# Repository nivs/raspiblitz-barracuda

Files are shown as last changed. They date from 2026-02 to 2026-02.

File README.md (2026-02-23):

[](https://github.com/user-attachments/assets/af210934-4651-4c5d-a316-91d5e0f595a6)

# RaspiBlitz Barracuda

A custom-built [RaspiBlitz](https://github.com/rootzoll/raspiblitz) - a DIY Bitcoin full node running together with a Lightning node on a Raspberry Pi - housed in a 3D-printed chassis with UPS battery backup, fan control, and an LCD touchscreen.

## Components

| Component | Notes |
|---|---|
| [Raspberry Pi 4](https://www.amazon.com/dp/B07TC2BK1X) (4GB or 8GB) | Main board |
| [SanDisk SSD PLUS 1TB](https://www.amazon.com/dp/B09NQJMW28) | Blockchain storage |
| [UGREEN 2.5" Hard Drive Enclosure](https://www.amazon.com/dp/B06XWRRMYX) | SSD enclosure |
| MicroSD Card 32GB | Boot drive |
| [Waveshare 3.5" RPi LCD (B)](https://www.waveshare.com/wiki/3.5inch_RPi_LCD_(B)) | Touchscreen display |
| [Raspberry Pi 4 Official PSU](https://www.amazon.com/dp/B07W8XHMJZ) | 15W USB-C power supply |
| [Dual Fan Heatsink Case](https://www.amazon.com/dp/B07VWM4J4L) | Cooling |
| [UPS Lite 18650](https://www.aliexpress.com/item/32955634965.html) ([GitHub](https://github.com/linshuqin329/UPS-18650-Lite)) | Battery backup |
| [USB 3.0 Micro-B Ribbon Cable](https://www.aliexpress.com/item/4001289178964.html) (S3-W7, USB-A male down, Micro-B up, 0.1m) | SSD connection |
| 40 Pin Stacking Header (8/6mm) | LCD clearance over heatsink |
| 4010 Cooling Fan 40mm | Additional cooling |
| Micro Mini JST 2.0 PH Connectors (3 & 4 pin) | UPS / fan wiring |
| 12mm LED Momentary Switch (6V, Yellow) | Power/reset button |
| 30 & 24 AWG Flexible Silicone Wire | Internal wiring |

<br>

## Setup

Follow the RaspiBlitz [setup instructions](https://docs.raspiblitz.org/docs/setup/intro) to install the software, then apply the hardware customizations below.

A full [connections schematic](raspiblitz-barracuda-connections.pdf) is included in the repo.
<br><br>

## 3D-Printed Chassis

Print files are in the [`chassis/`](chassis/) directory:

- `chassis.3mf` - main enclosure
- `cover.3mf` - top cover
- `lightning-bolt.3mf` - decorative emblem
- `barracuda.f3d` - Fusion 360 source

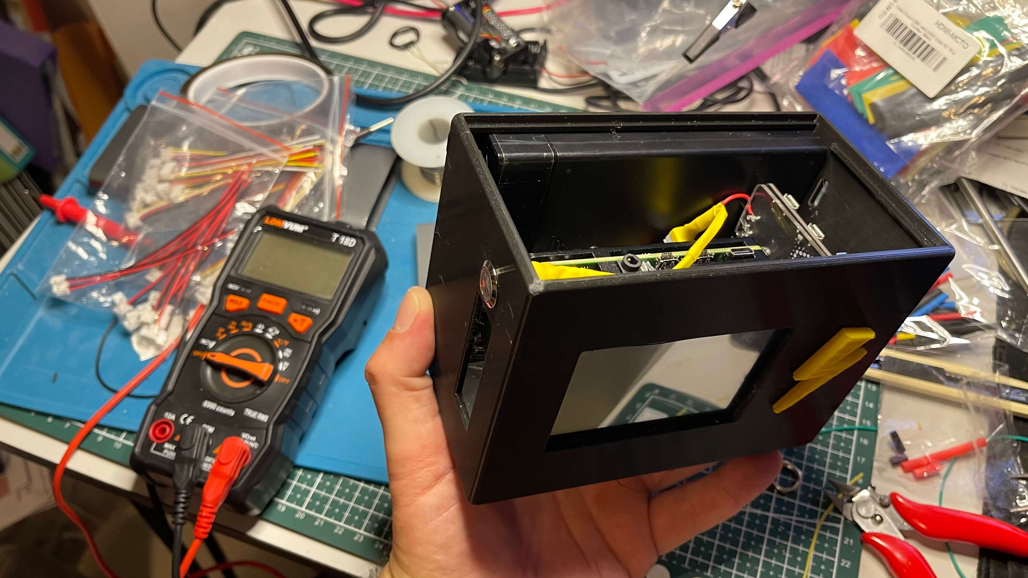
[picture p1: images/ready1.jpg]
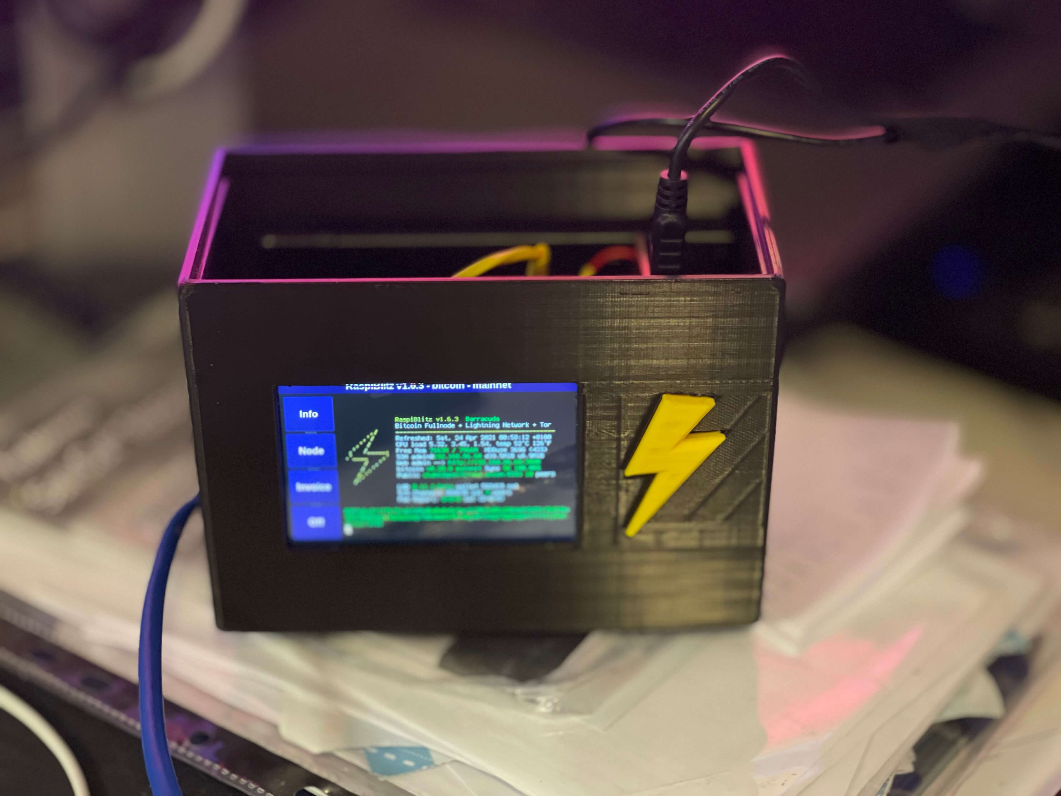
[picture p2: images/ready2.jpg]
 
<br><br>

## Power-On / Reset Switch

Connect a momentary switch between **GPIO3** and **GND**. Use a switch with an integrated LED for the activity indicator.

Alternatively, you can connect the momentary switch to the UPS's power switch, but this is suboptimal as it will not trigger the `gpio-shutdown` event.

See [SHUTDOWN.md](SHUTDOWN.md) for more details.

### Activity LED

1. Connect an LED to **GPIO16** via a 220 ohm resistor.
2. Add to `/boot/config.txt`:
   ```
   dtparam=act_led_gpio=16
   ```

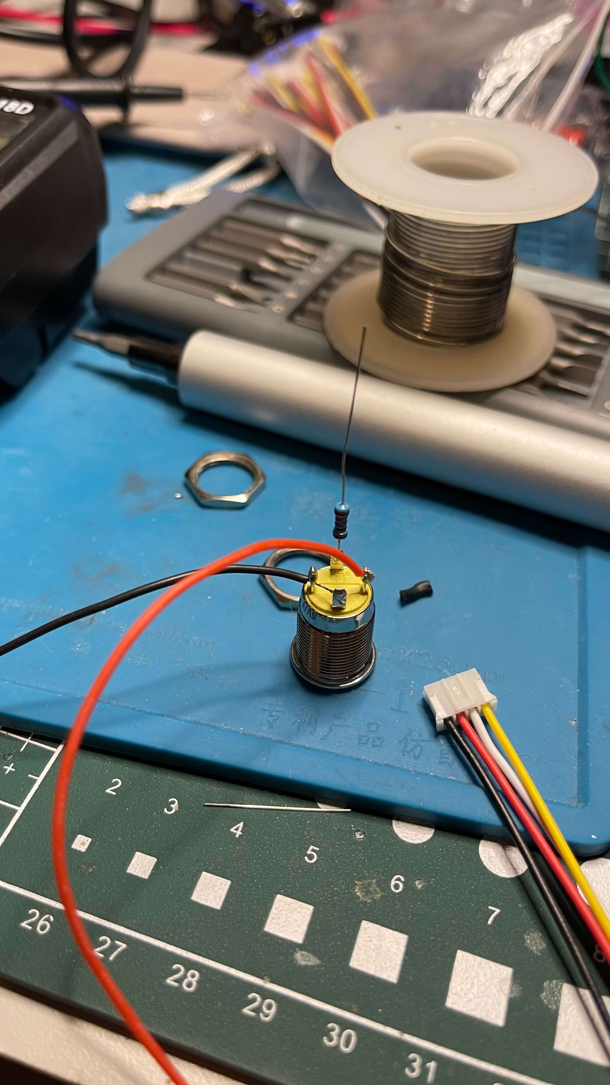
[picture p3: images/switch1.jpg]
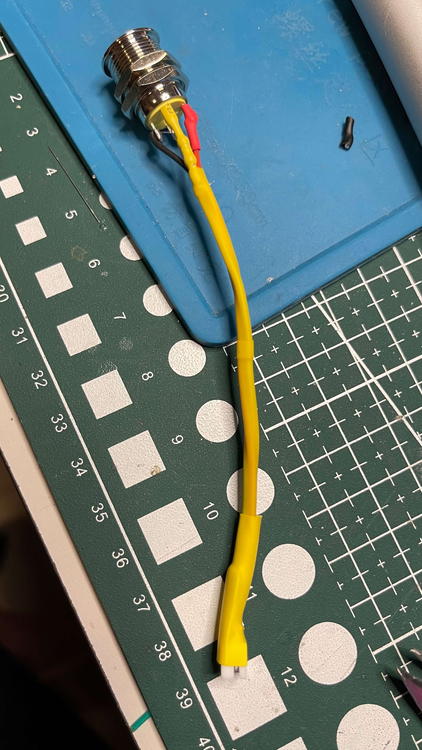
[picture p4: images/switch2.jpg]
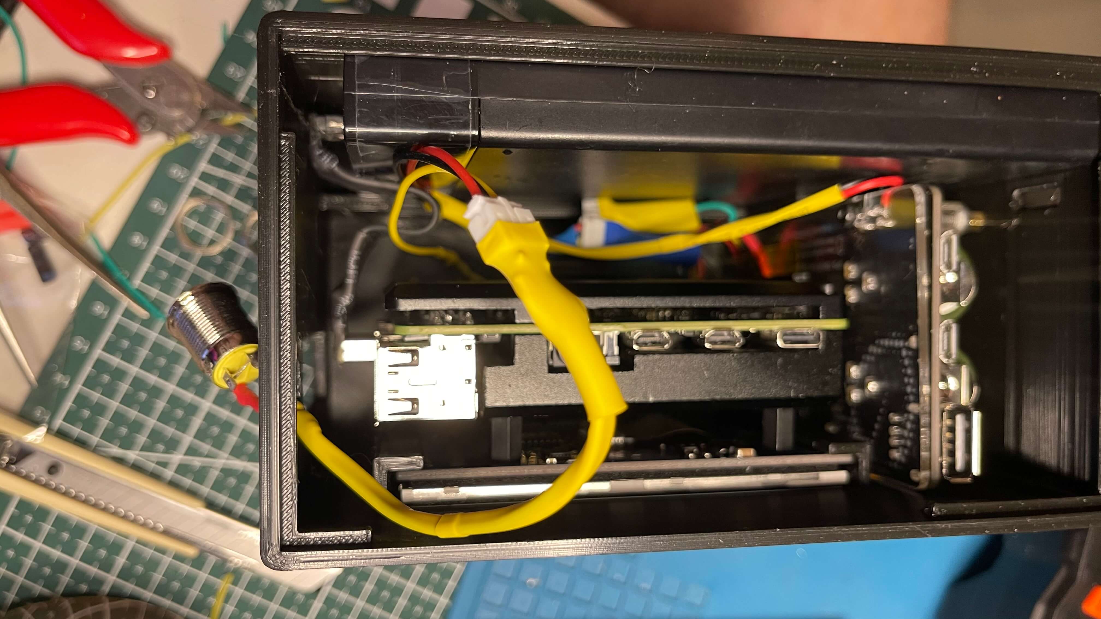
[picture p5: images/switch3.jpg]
  
<br><br>

## Fan Control

Connect **GPIO14** via a 1k ohm resistor to a BC547 transistor to switch the fans (heatsink case fans or an additional external one).

Add to `/boot/config.txt`:
```
dtoverlay=gpio-fan,gpiopin=14,temp=60000
```

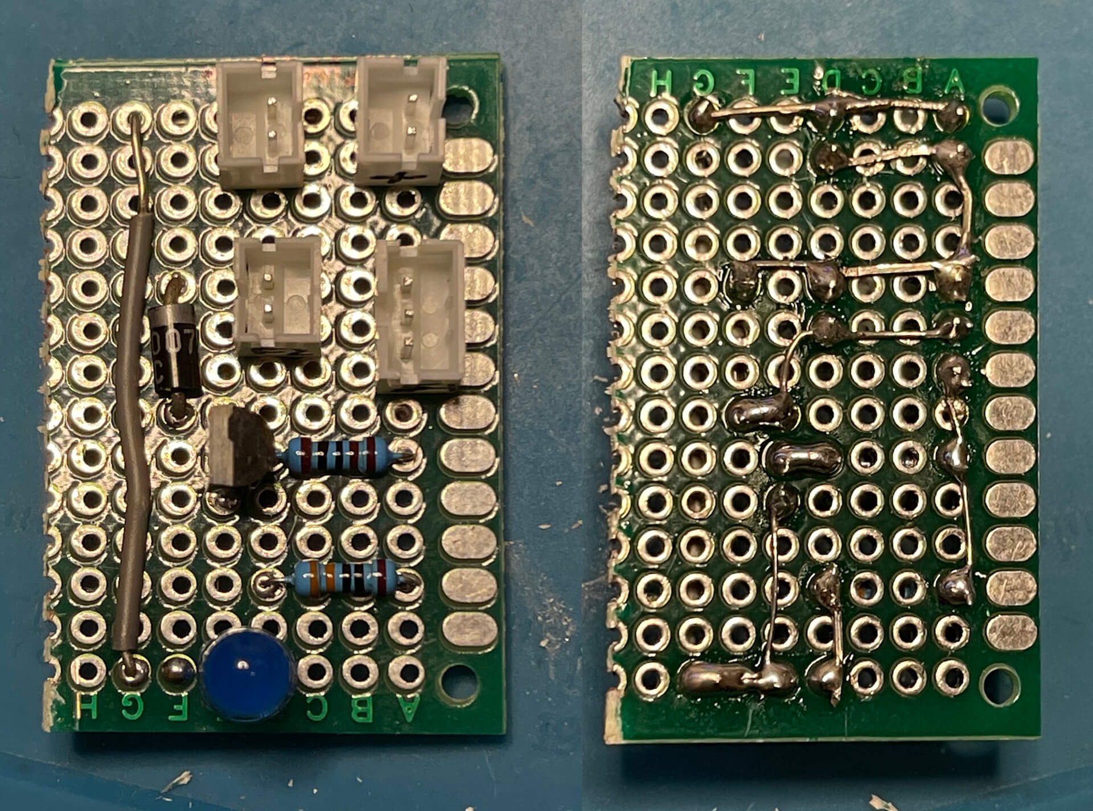
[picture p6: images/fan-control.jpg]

<br>

## LCD

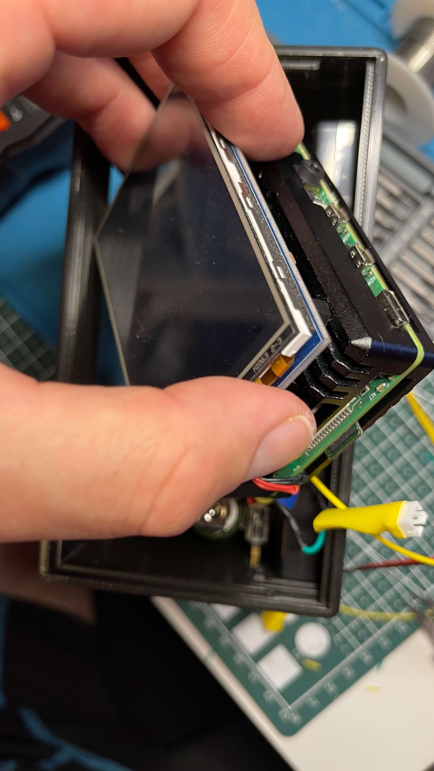
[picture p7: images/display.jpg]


Follow the [Waveshare setup instructions](https://www.waveshare.com/wiki/3.5inch_RPi_LCD_(B)#Software_Settings).

### Backlight Brightness

1. Short the jumper as described in the [Waveshare documentation](https://www.waveshare.com/wiki/3.5inch_RPi_LCD_(B)#Control_Backlight_Brightness_Using_GPIO).
2. Use [`brightness.sh`](brightness.sh) to set brightness (0–1024):
   ```bash
   ./brightness.sh 800
   ```
<br>

## UPS Lite 18650

In this build the UPS Lite is **not** mounted as a HAT - it is wired directly:

- **GPIO2 / GPIO3 (I2C)** - battery state readout
- **GPIO4** - external power detection

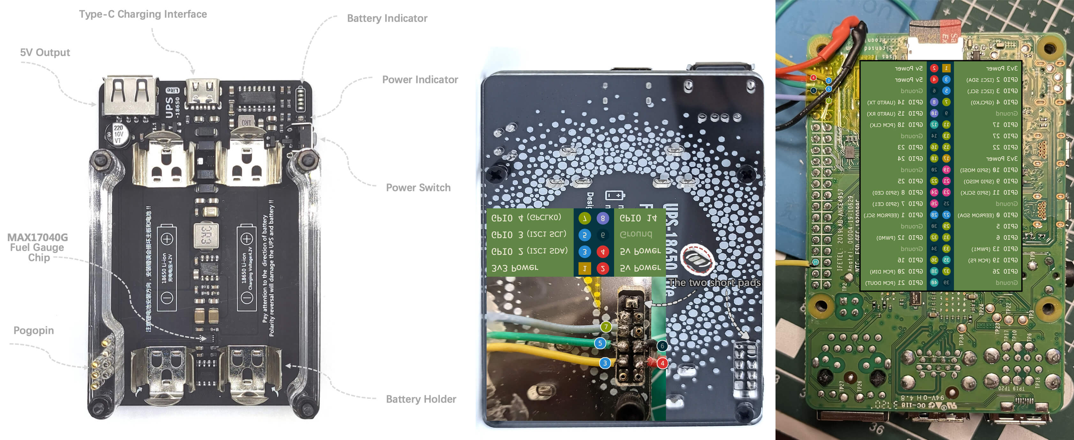
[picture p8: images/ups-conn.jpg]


See the [wiring photo](images/ups-conn.jpg).

### External Power Detection

Short the jumper as described in the [UPS Lite documentation](UPS-18650-Lite/Instructions%20for%20UPS-18650-Lite%20V1.2.pdf). The external power state can be read via **GPIO4**.

### Auto Shutdown

A systemd service monitors battery capacity and triggers a safe shutdown at 1% to prevent data corruption before the hardware protection cuts power.

#### Setup

1. **Enable I2C:**
   ```bash
   # Add or uncomment in /boot/config.txt:
   dtparam=i2c_arm=on

   # Add to /etc/modules (if not already present):
   echo "i2c-dev" | sudo tee -a /etc/modules

   sudo reboot
   ```
2. **Verify I2C** (should show `0x36` for the MAX17040G fuel gauge):
   ```bash
   sudo apt install -y i2c-tools
   sudo i2cdetect -y 1
   ```
3. **Install the monitor service:**
   ```bash
   cp UPS-18650-Lite/ups_shutdown.py /home/pi/
   sudo cp UPS-18650-Lite/ups_monitor.service /etc/systemd/system/
   sudo systemctl daemon-reload
   sudo systemctl enable --now ups_monitor.service
   ```
4. **Verify:**
   ```bash
   sudo systemctl status ups_monitor.service
   sudo journalctl -u ups_monitor.service -n 50
   ```

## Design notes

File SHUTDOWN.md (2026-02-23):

# Shutdown Raspberry Pi with a Single Button

Connect [Boot Button](https://pinout.xyz/pinout/pin5_gpio3#) via a momentary switch to GND:
- Physical/Board pin 5 - GPIO/BCM pin 3 (this is [I2C](https://pinout.xyz/pinout/i2c#)1/SCL, so I2C will be disturbed by a button press)
- GND pin 6

## Boot Overlay

In system version 225 and above, power-down and power-up is possible via shorting [GPIO3 (pin 5)](https://pinout.xyz/pinout/pin5_gpio3#). 
This functionality is enabled by adding the following line to `/boot/config.txt` and restarting:

```
dtoverlay=gpio-shutdown,gpio_pin=3
```

Note: the qualifier `gpio_pin=3` is redundant since this pin is the default.

GPIO3 has an external pull-up, so shorting to ground briefly will initiate a shutdown.  
A subsequent short to ground (provided power is still applied) will power-on the system.

The [boot overlay documentation](https://github.com/raspberrypi/firmware/blob/master/boot/overlays/README) for this function is as follows:

```
Name:   gpio-shutdown
Info:   Initiates a shutdown when GPIO pin changes. The given GPIO pin
        is configured as an input key that generates KEY_POWER events.

        This event is handled by systemd-logind by initiating a
        shutdown. Systemd versions older than 225 need an udev rule
        enable listening to the input device:

                ACTION!="REMOVE", SUBSYSTEM=="input", KERNEL=="event*", \
                        SUBSYSTEMS=="platform", DRIVERS=="gpio-keys", \
                        ATTRS{keys}=="116", TAG+="power-switch"

        Alternatively this event can be handled also on systems without
        systemd, just by traditional SysV init daemon. KEY_POWER event
        (keycode 116) needs to be mapped to KeyboardSignal on console
        and then kb::kbrequest inittab action which is triggered by
        KeyboardSignal from console can be configured to issue system
        shutdown. Steps for this configuration are:

            Add following lines to the /etc/console-setup/remap.inc file:

                # Key Power as special keypress
                keycode 116 = KeyboardSignal

            Then add following lines to /etc/inittab file:

                # Action on special keypress (Key Power)
                kb::kbrequest:/sbin/shutdown -t1 -a -h -P now

            And finally reload configuration by calling following commands:

                # dpkg-reconfigure console-setup
                # service console-setup reload
                # init q

        This overlay only handles shutdown. After shutdown, the system
        can be powered up again by driving GPIO3 low. The default
        configuration uses GPIO3 with a pullup, so if you connect a
        button between GPIO3 and GND (pin 5 and 6 on the 40-pin header),
        you get a shutdown and power-up button. Please note that
        Raspberry Pi 1 Model B rev 1 uses GPIO1 instead of GPIO3.
Load:   dtoverlay=gpio-shutdown,<param>=<val>
Params: gpio_pin                GPIO pin to trigger on (default 3)
                                For Raspberry Pi 1 Model B rev 1 set this
                                explicitly to value 1, e.g.:

                                    dtoverlay=gpio-shutdown,gpio_pin=1

        active_low              When this is 1 (active low), a falling
                                edge generates a key down event and a
                                rising edge generates a key up event.
                                When this is 0 (active high), this is
                                reversed. The default is 1 (active low).

        gpio_pull               Desired pull-up/down state (off, down, up)
                                Default is "up".

                                Note that the default pin (GPIO3) has an
                                external pullup. Same applies for GPIO1
                                on Raspberry Pi 1 Model B rev 1.

        debounce                Specify the debounce interval in milliseconds
                                (default 100)
```

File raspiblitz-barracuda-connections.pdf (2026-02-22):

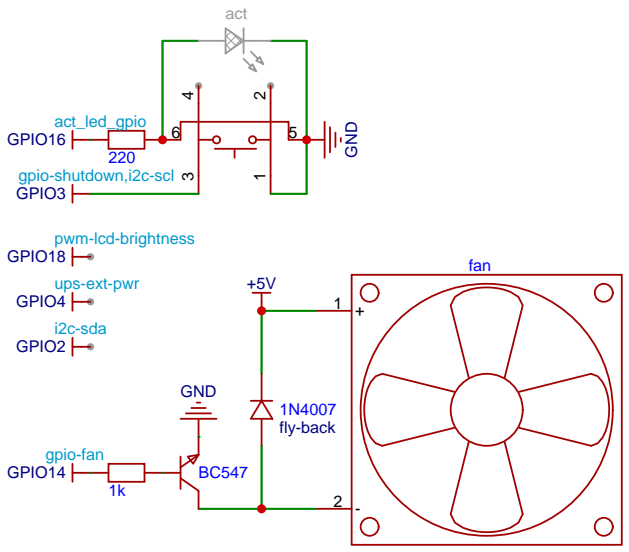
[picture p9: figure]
fan; 1N4007 fly-back; GPIO14; gpio-fan; GND; GPIO16; act_led_gpio; GPIO3; gpio-shutdown,i2c-scl; GPIO18; pwm-lcd-brightness; GPIO4; ups-ext-pwr; GPIO2; i2c-sda; act

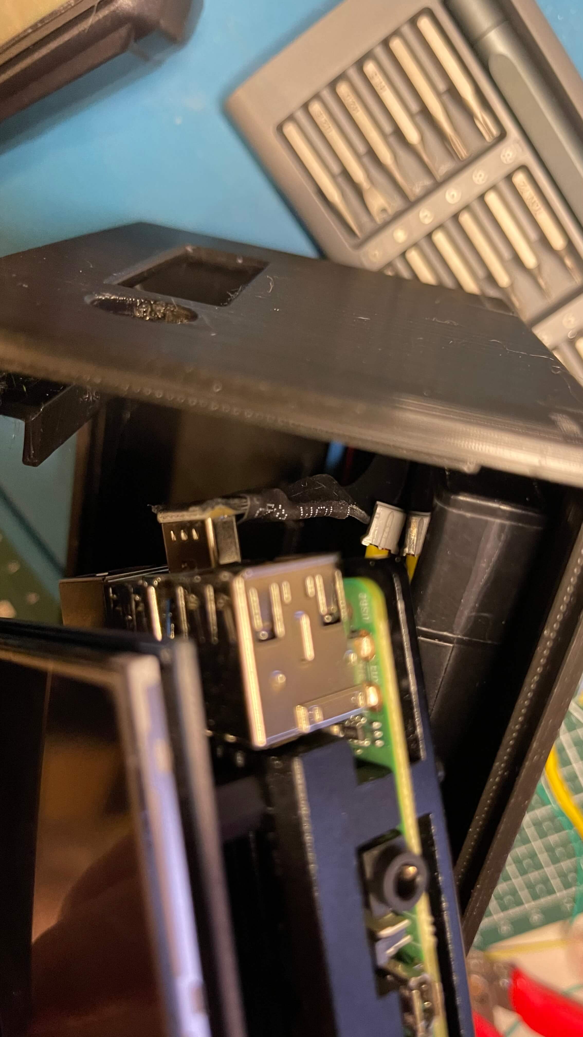
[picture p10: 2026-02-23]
images/usb-c-ribbon2.jpg

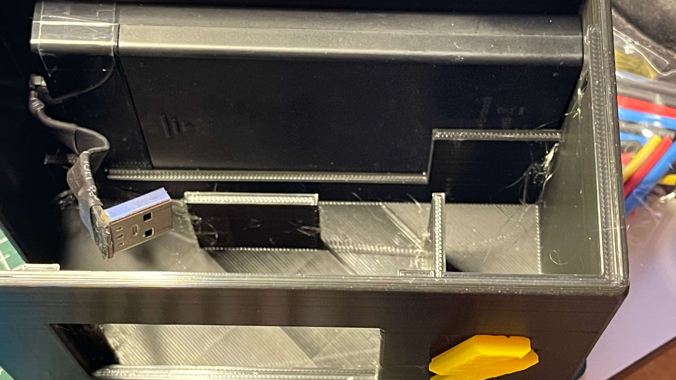
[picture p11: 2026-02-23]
images/usb-c-ribbon1.jpg

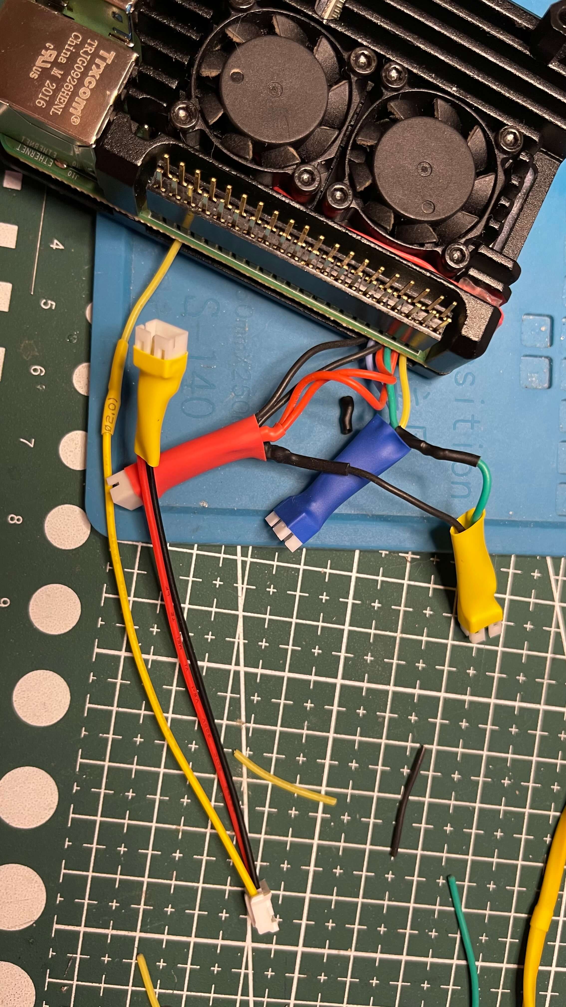
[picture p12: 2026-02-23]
images/raspberry-pi-conn.jpg

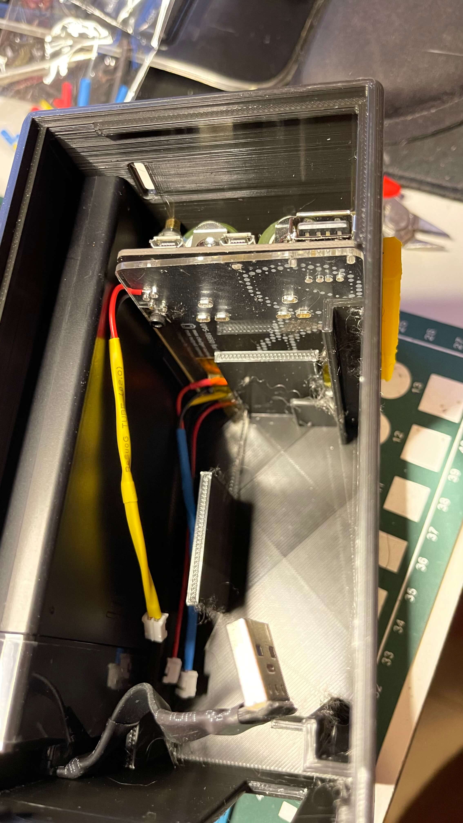
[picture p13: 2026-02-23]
images/ups-hdd.jpg

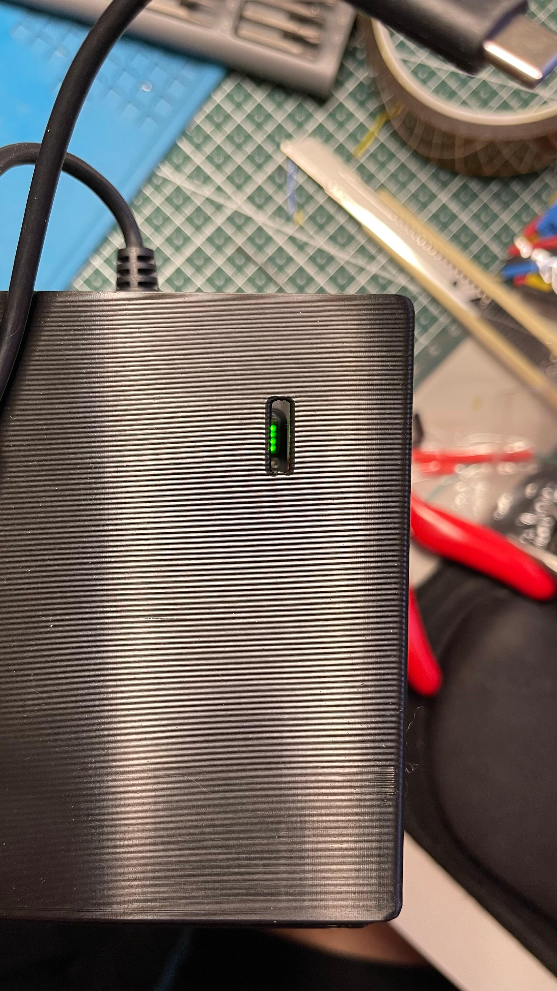
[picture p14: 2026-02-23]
images/ups-battery-indicator.jpg

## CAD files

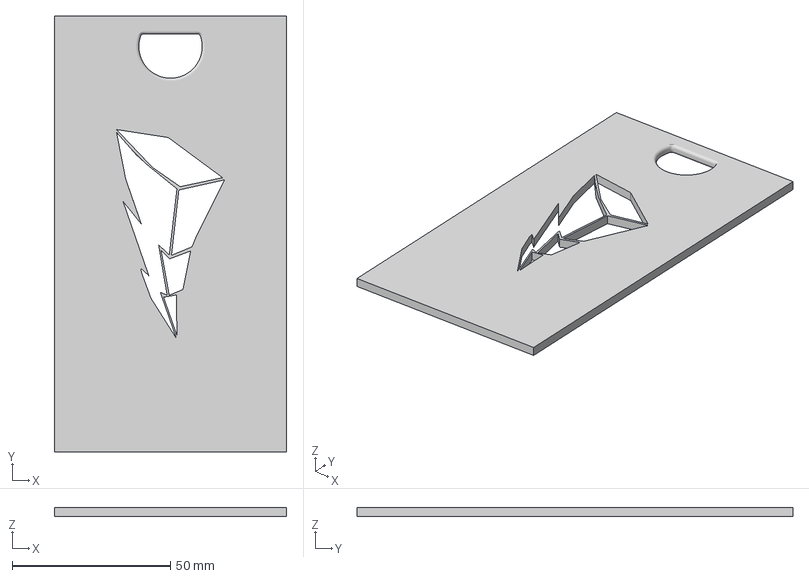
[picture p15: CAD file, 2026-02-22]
chassis/cover.3mf
73.4 x 137.9 x 3.00 mm

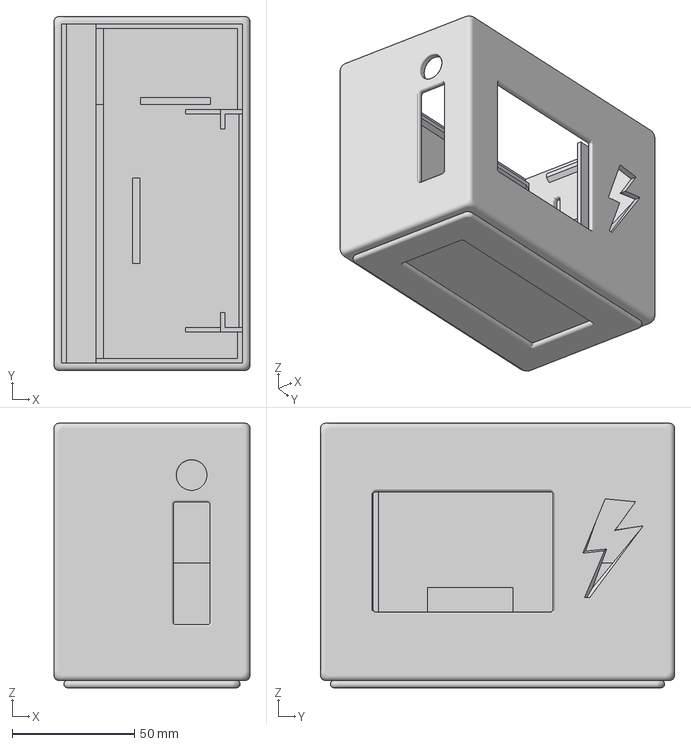
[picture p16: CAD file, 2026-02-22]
chassis/chassis.3mf
80.0 x 144.5 x 108.0 mm

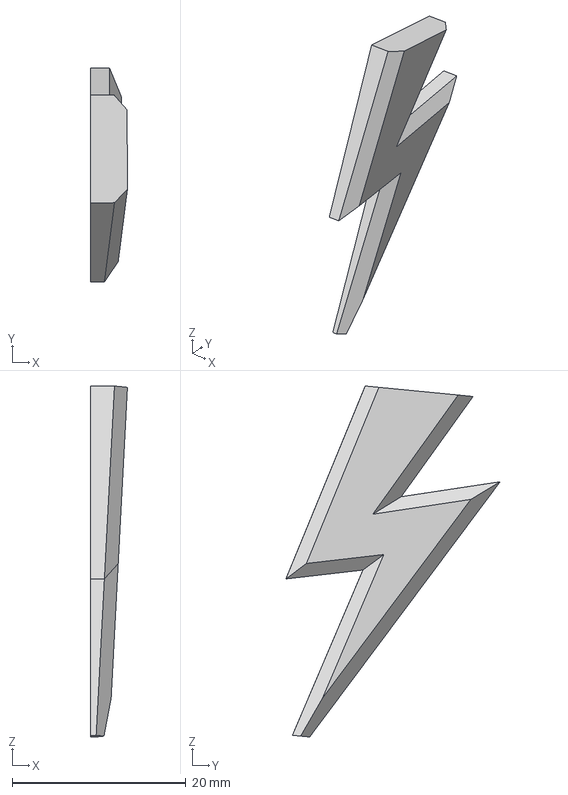
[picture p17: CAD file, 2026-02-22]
chassis/lightning-bolt.3mf
4.25 x 24.7 x 40.4 mm

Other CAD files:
chassis/barracuda.f3d

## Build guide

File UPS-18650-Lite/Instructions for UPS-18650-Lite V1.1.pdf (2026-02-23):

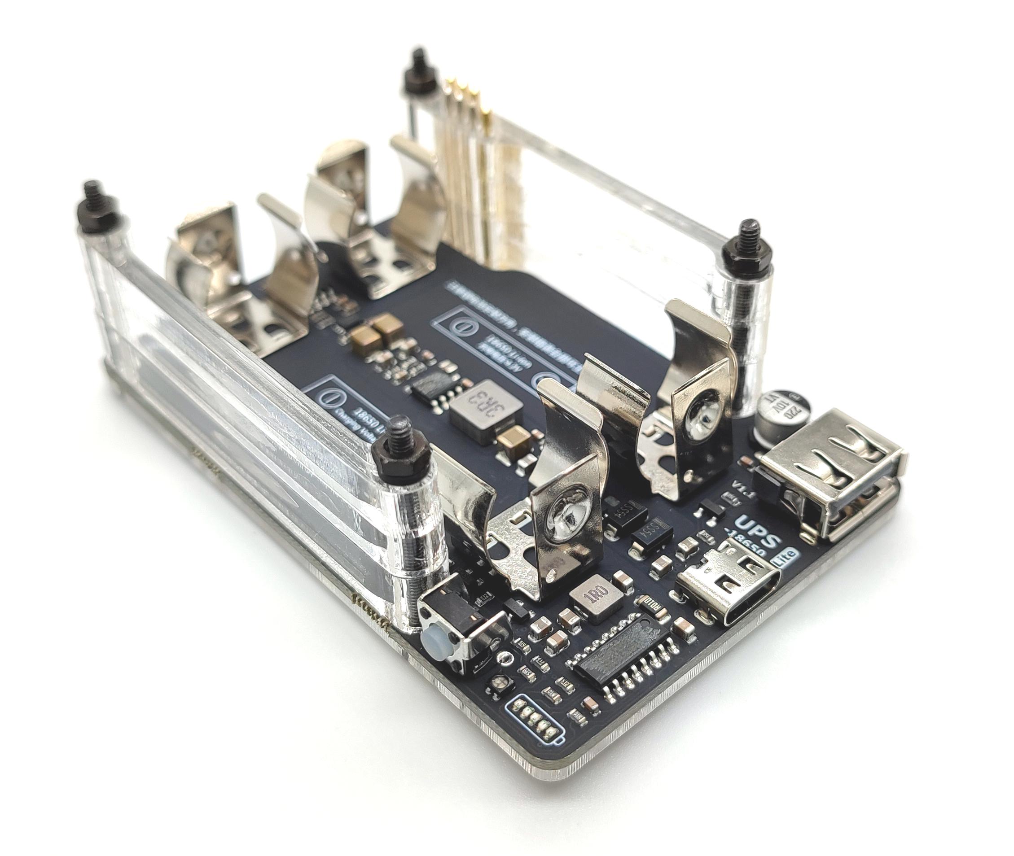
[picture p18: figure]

# 1. Introduction

UPS-18650-Lite is a UPS power supply specially designed for Raspberry Pi model B series boards (namely 4B/3B+/3B, etc., hereinafter referred to as pi). It uses two standard flat-head 18650 lithium batteries for power supply. It support over-charge, over-discharge, over-current, short-circuit protection, support external power plug-in detection, support charging and discharging, when the external power is plugged in, the pi is powered by the external power source, when the external power source is unplugged, the pi seamlessly switches to the lithium battery power supply . UPS-18650-Lite is connected to the pi through 7 pogopins. The power supply and battery power measurement functions of the pi are all done

through pogopins. The pi does not need to plug any power cords, just plug the external power cord into the UPS type-C port ,it can complete power supply and charging by the UPS. In addition, UPS-18650-Lite integrates the professional fuel gauge chip MAX17040G, which can be used to measure UPS battery voltage and battery remaining power.

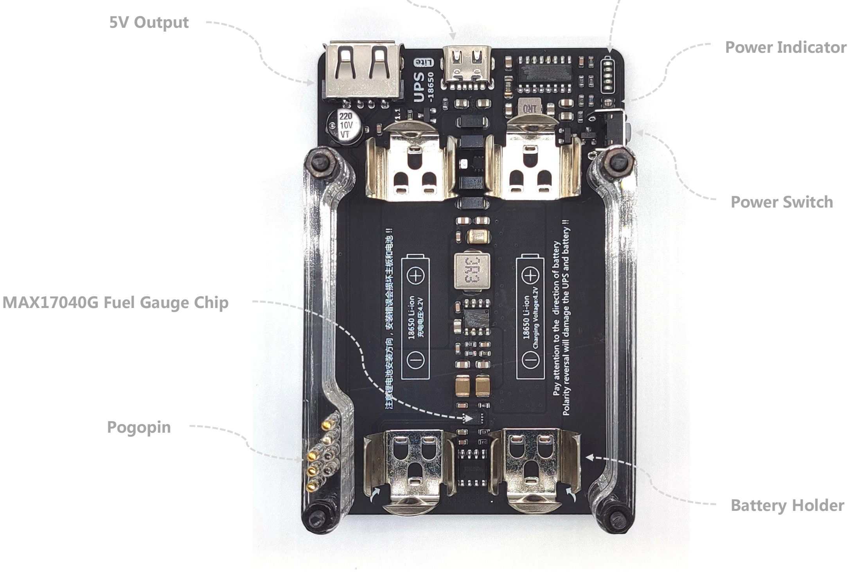
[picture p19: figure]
Power Indicator 5V Output; MAX17040G Fuel Gauge Chip

Battery Holder

Power Switch

Battery Indicator Type-C Charging Interface

Pogopin

Parameter :
Charging current: Max 1A@5V
Output current: Instant Discharge 3.5A@5.1V, Continuous Discharge 2.5A@5.1V
(PS: Please use good quality batteries and power adapters to ensure that the UPS works normally)

Battery measurement: Percentage of battery SOC, an error ±2%, The measurement errors of battery voltages ± 3mV

(PS: The measurement error varies with the individual battery and the ambient temperature)

# 2. Install

a. Please install two 18650 lithium batteries in the direction of the battery logo on the board. Pay attention to the battery direction when installing. Incorrect installation will burn the board and the battery! ! ! (PS: The two lithium batteries must be standard flat-head 18650 batteries of the same type with similar internal resistance and capacity. Two lithium batteries with different parameters cannot be mixed, and lithium batteries with protective plates cannot be used)

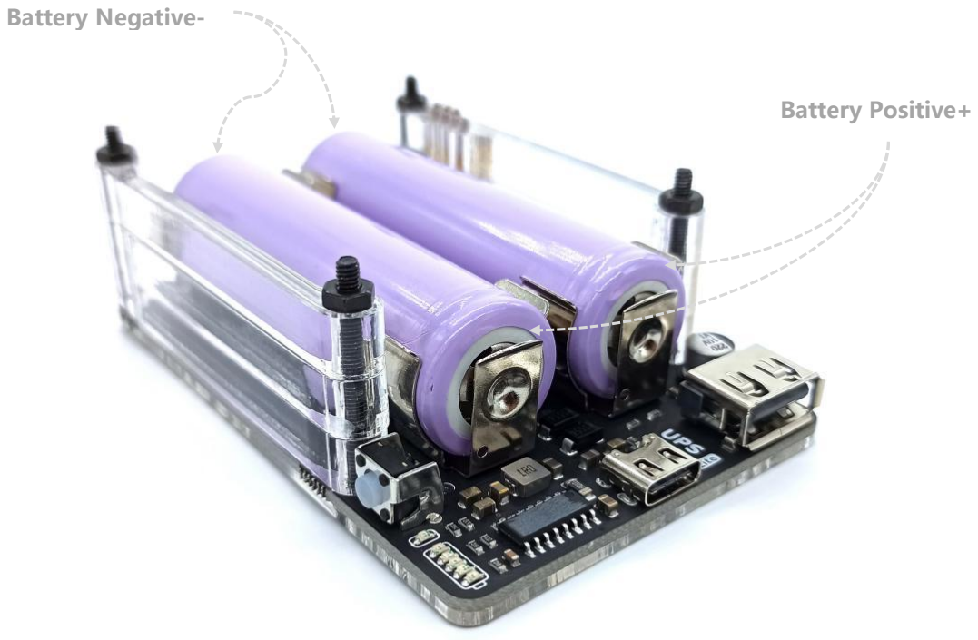
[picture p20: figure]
Battery Negative-; Battery Positive+
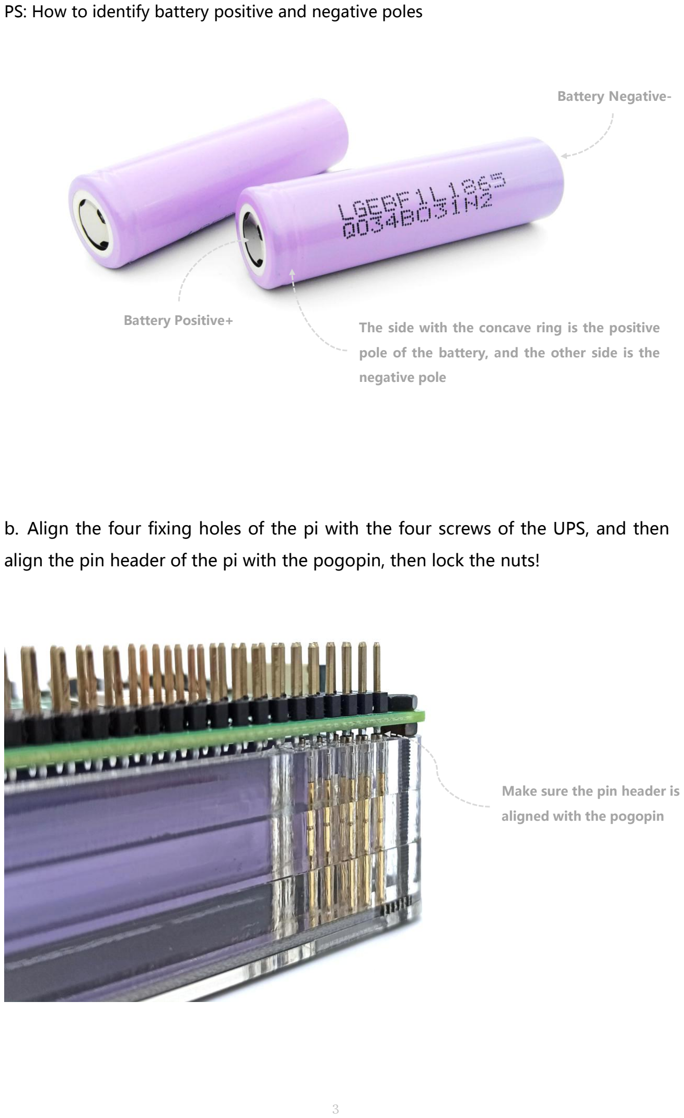
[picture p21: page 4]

PS: How to identify battery positive and negative poles

b. Align the four fixing holes of the pi with the four screws of the UPS, and then align the pin header of the pi with the pogopin, then lock the nuts!

Battery Positive+

Battery Negative-

Make sure the pin header is aligned with the pogopin

The side with the concave ring is the positive pole of the battery, and the other side is the negative pole

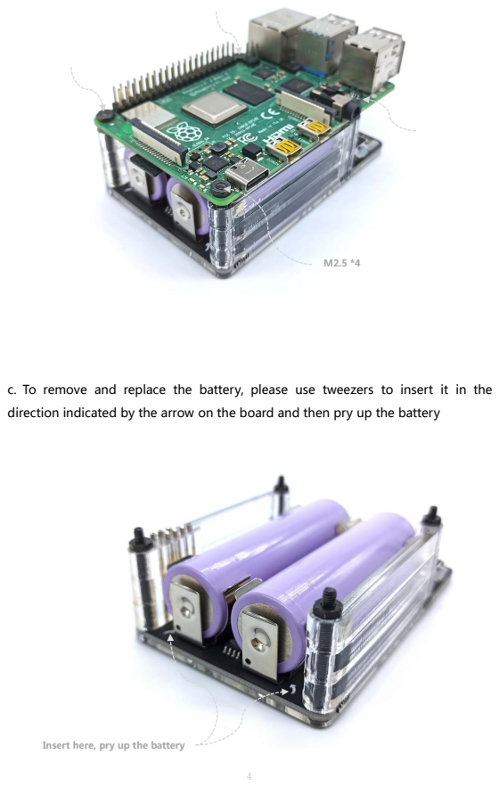
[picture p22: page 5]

c. To remove and replace the battery, please use tweezers to insert it in the
direction indicated by the arrow on the board and then pry up the battery

Insert here, pry up the battery

# 3.Function and using

### 3.1 Charging and Power Insertion Detection

It is recommended to use a power adapter with a power of 5V3A and above to charge the UPS-18650-Lite. Because when the lithium battery is low, the external power adapter not only needs to supply power to the pi, but also needs to provide part of the current to charge the lithium battery. During the charging , the battery indicator will flash one after another. When the lithium battery is fully charged, the 5 green battery indicators will all light up, indicating that the battery is fully charged. The battery capacity indicated by the 5 battery indicators is 20%, 40%, 60%, 80%, and 100%. UPS-18650-Lite has an external power adapter insertion detection function. When the external power supply is plugged in, the blue indicator light is on. You

can judge whether the external power supply is inserted by the high and low levels of the GPIO port. When the power supply is plugged in, the io4 (BCM mode) of the pi will detect a low level. When unplugging ,the pi will detect a high level, to enable the detection function, the two pads on the back of the UPS must be shorted, and the GPIO is set to the input state. If the pad is not shorted, the state of the GPIO detection is unstable. See the following figure for details.

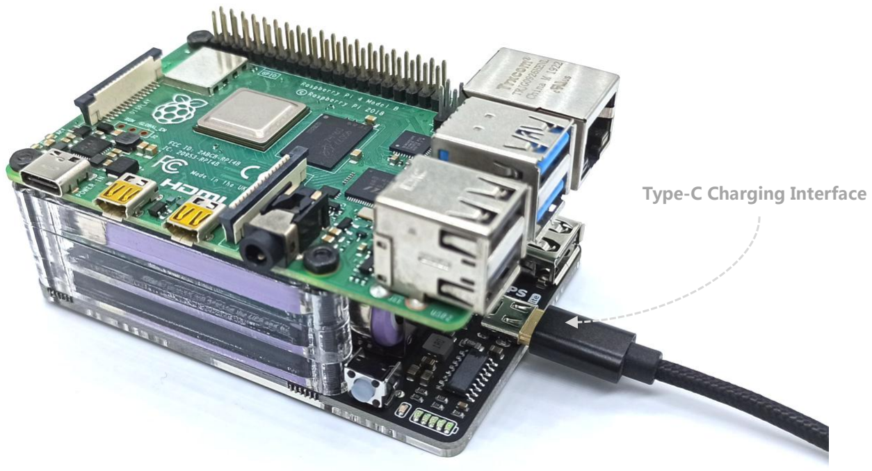
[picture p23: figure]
Type-C Charging Interface

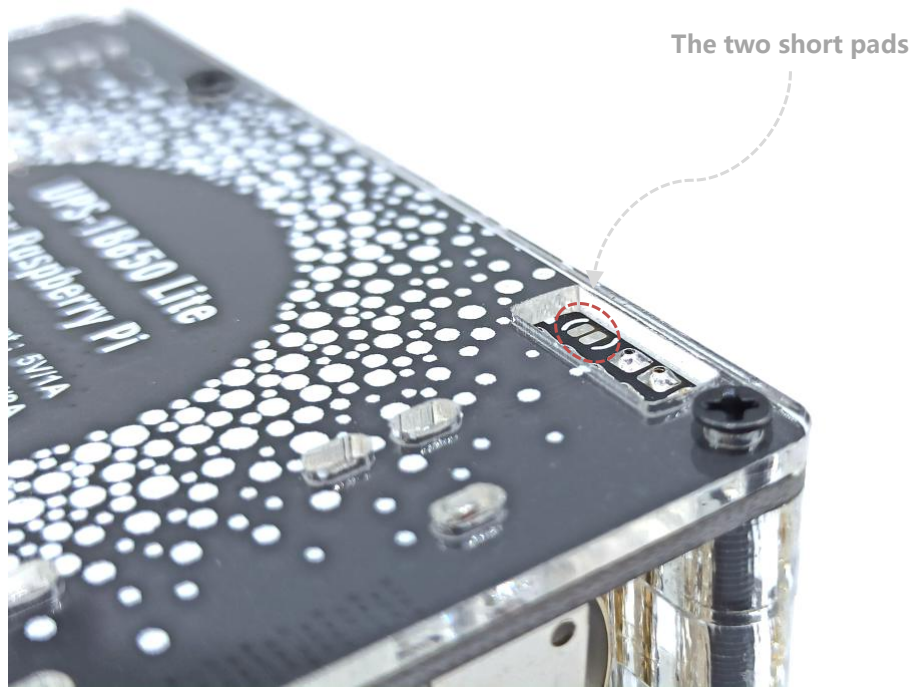
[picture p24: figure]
The two short pads

### 3.2 Power Output Operation

When the external power adapter is plug in, press and hold the power switch for more than 3 seconds, the red power indicator light will be on, indicatingthat the 5V voltage output is turned on. Press and hold again for more than 3 seconds, the red power indicator light is off, indicating that the 5V voltage output is turned off. When the external power adapter is unplug, press and hold the power switch

for more than 3 seconds, the red power indicator light will be on, indicatingthat the 5V voltage output is turned on. Press and hold again for more than 3 seconds, the red power indicator light is off, indicating that the 5V voltage output is turned off. You can also turn off the 5V voltage output by quick double click the power switch. Short click the power switch once, the power indicator shows the battery power, and it will go out later. The output power of the booster circuit of UPS-18650-Lite is affected by

factors such as battery voltage, battery discharge current, external power supply power, and power cord voltage drop. Therefore, it is recommended to use a high-quality 18650 battery with a large discharge current for power supply. In addition, in order to improve the circuit boost efficiency, it is recommended that the power line choose a line with a small line voltage drop, so as to minimize the power consumption caused by the line voltage drop.

The continuous output current of UPS-18650-Lite is 2.5A, and the instantaneous maximum output current is 3.5A. In the case of continuous high current output for a long time, please take heat dissipation measures and use it in a ventilated place as much as possible to avoid high temperature causing thermal shutdown protection and affect battery life.

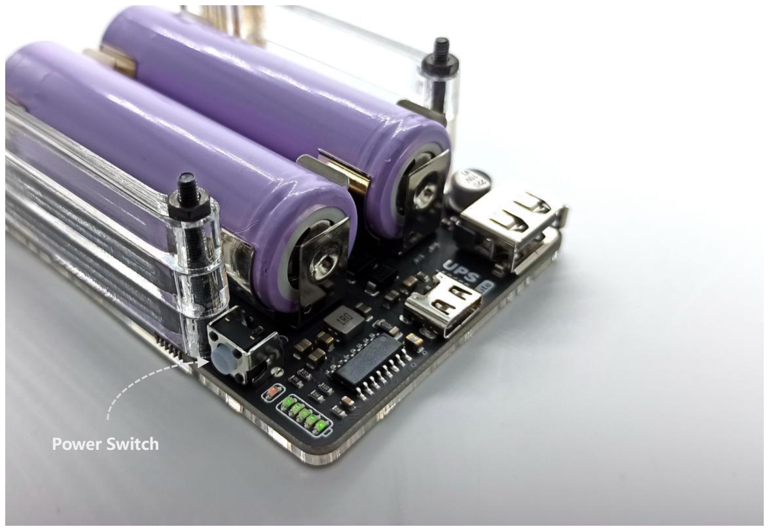
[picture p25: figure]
Power Switch

### 3.3 Battery Power Measurement

Create a script program named UPS_18650_Lite.py with the nano editor. The code is as follows (see appendix for detailed code). This script uses Python's smbus library to perform i2c read operations on the MAX17040G. The MAX17040G device address is 0x36, the register VCELL is the 12bit battery voltage ADC measurement value, the address is 02h-03h, and the ADC measurement accuracy unit is 1.25mV. The register SOC is a 16-bit battery capacity percentage reading, The address is

04h-05h. The upper 8-bit unit of the SOC is 1% of the battery capacity, and the lower 8-bit unit is 1/256%. It provides the reading of the decimal point of the battery capacity percentage. Save the UPS_18650_Lite.py script program to a directory you know (such as the following to the /home/pi/ directory), then run the program in Python, you can see that the program will output the current battery voltage value and the percentage of battery capacity every two seconds. In addition, due to the calculation method of the MAX17040G battery capacity, when the battery capacity reading is 1%, the battery voltage reading is about 3.5V. When the voltage of the lithium battery is 3.5V, the corresponding battery capacity is already very low, and excessive discharge will damage the battery. Therefore, when the user subsequently writes a low-power automatic shutdown program, it is recommended to automatically turn off the pi when the battery capacity is 1%. When running, when the battery voltage drops to 3V, the UPS-Lite protection

circuit will automatically stop supplying power. See below for specific steps

MAX17040G register address and Features

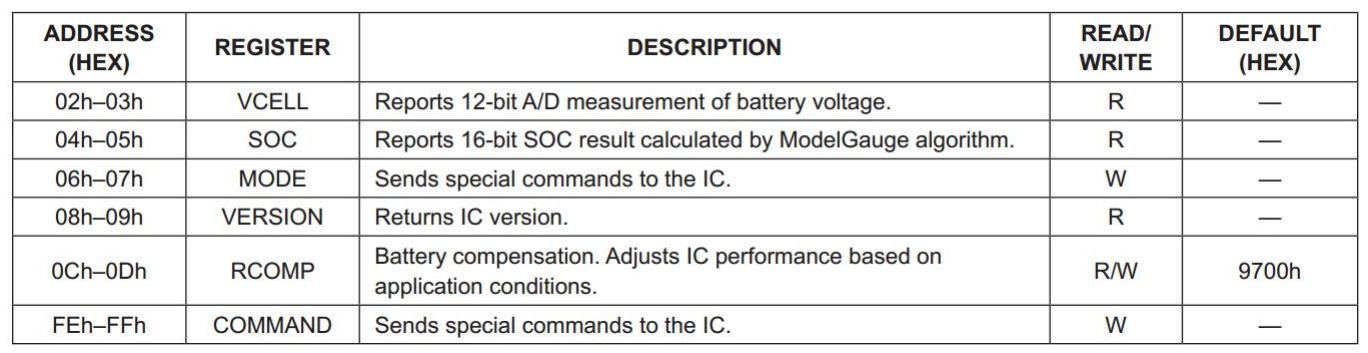
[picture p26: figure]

VCELL register

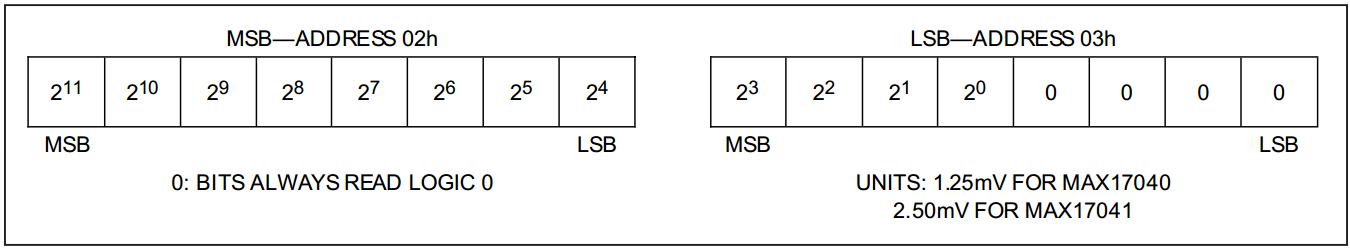
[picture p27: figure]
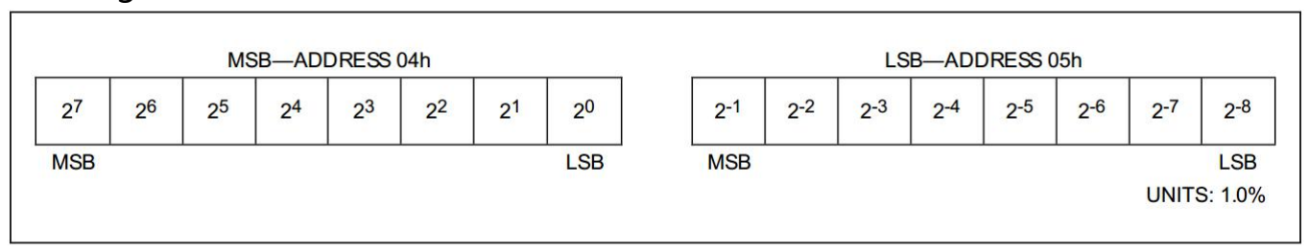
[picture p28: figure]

SOC register

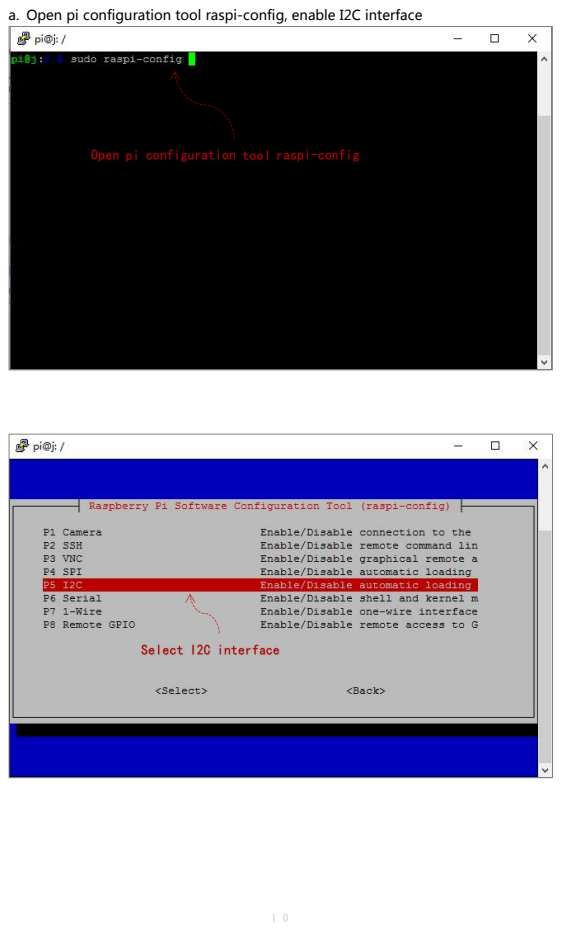
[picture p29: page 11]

a. Open pi configuration tool raspi-config, enable I2C interface

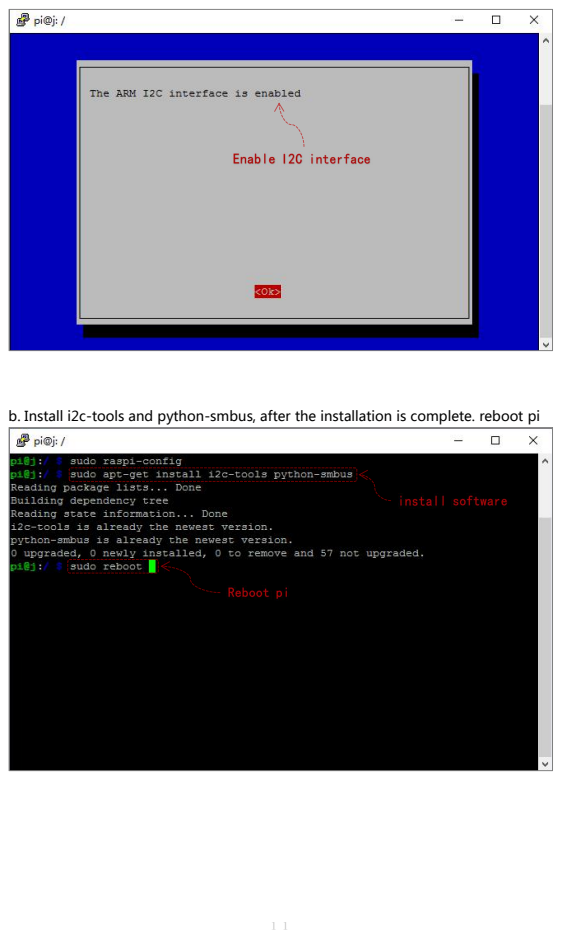
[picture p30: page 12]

b. Install i2c-tools and python-smbus, after the installation is complete. reboot pi

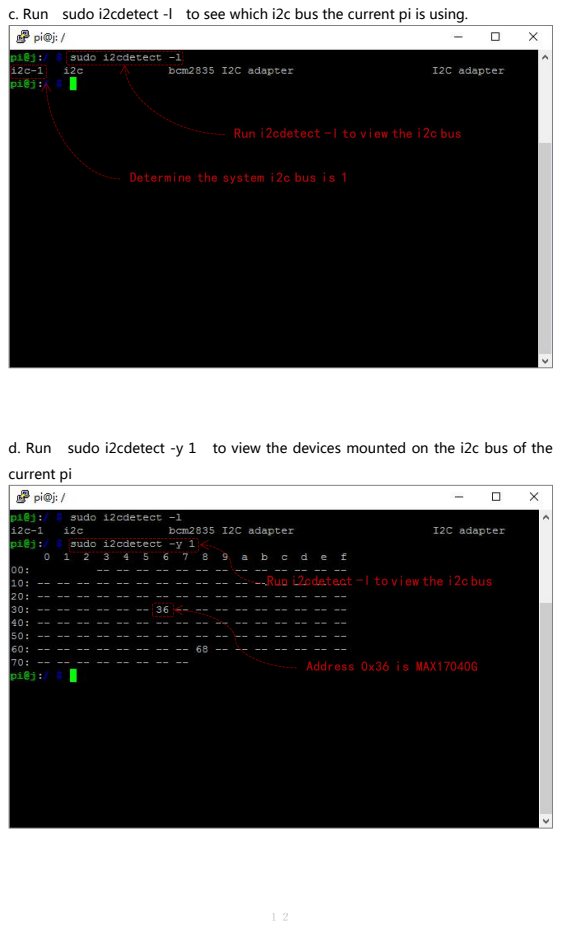
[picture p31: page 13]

c. Run sudo i2cdetect -l to see which i2c bus the current pi is using.

d. Run sudo i2cdetect -y 1 to view the devices mounted on the i2c bus of the
current pi

e. Use nano editor to create the following UPS_Lite.py script program (see appendix for detailed code)

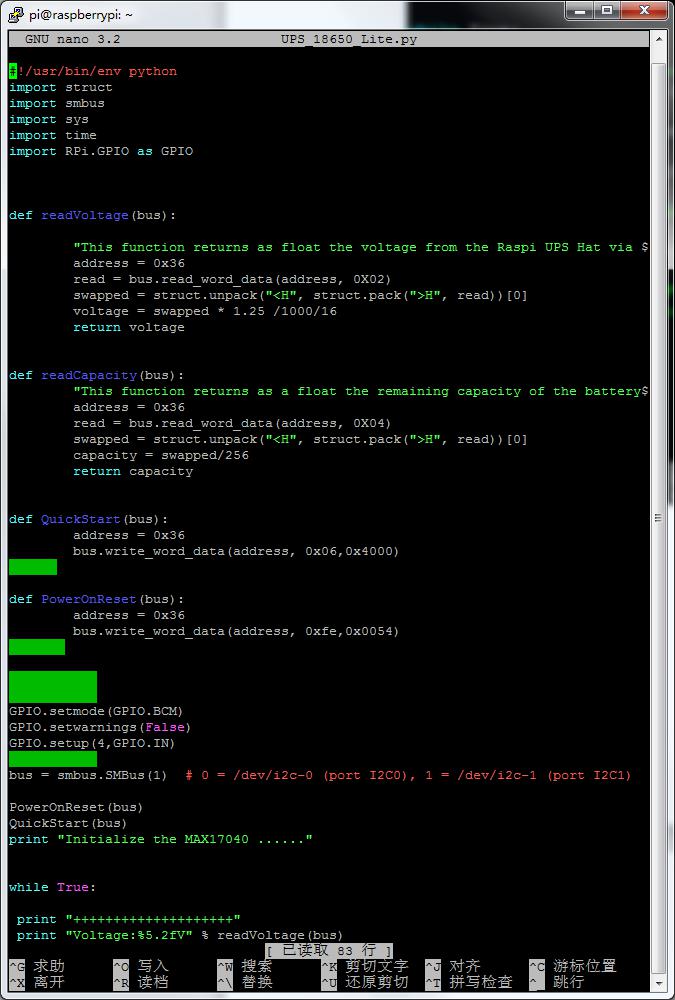
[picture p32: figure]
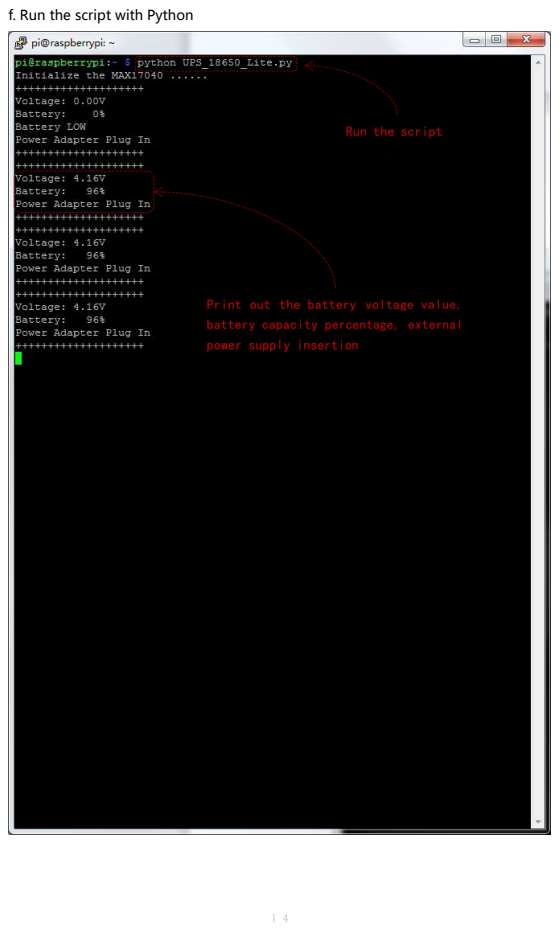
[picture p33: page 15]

f. Run the script with Python

# appendix：

Script code of UPS_18650_Lite.py：

#!/usr/bin/env | python

import | struct
import | smbus
import | sys
import | time
import | RPi.GPIO | as | GPIO
def | readVoltage(bus):
| | | "This | function | returns | as | float | the | | voltage | from | the | Raspi | UPS | Hat | via | the
provided | SMBus | object"
| | | address | = | 0x36
| | | read | = | bus.read_word_data(address, | | | | 0X02)
| | | swapped | = | struct.unpack("<H", | | | | struct.pack(">H", | | | | read))[0]
| | | voltage | = | swapped | * | 1.25 | /1000/16
| | | return | voltage
def | readCapacity(bus): "This function returns as a float the remaining capacity of the battery connected
to | the | Raspi | UPS | Hat | via | the | provided | SMBus | object"
| | | | address | = | 0x36
| | | | read | = | bus.read_word_data(address, | | | | 0X04)
| | | | swapped | = | struct.unpack("<H", | | | | struct.pack(">H", | read))[0]
| | | | capacity | = | swapped/256
| | | | return | capacity
def | QuickStart(bus):
| | address | = | 0x36
| | bus.write_word_data(address, | | | 0x06,0x4000)
def | PowerOnReset(bus):
| | address | = | 0x36
| | bus.write_word_data(address, | | | 0xfe,0x0054)

GPIO.setmode(GPIO.BCM)
GPIO.setwarnings(False)
GPIO.setup(4,GPIO.IN)
bus | = | smbus.SMBus(1) | # | 0 | = | /dev/i2c-0 | (port | I2C0), | 1 | = | /dev/i2c-1 | (port | I2C1)
print | " | | "
print | "Initialize | the | | MAX17040 | ......"
# | The | | following | is | the | | power | | plug | detection | judgment | program | of | V1.0 | version. | GPIO | is

high | | when | | power | | is | | plugged | | in
#if | | (GPIO.input(4) | | == | | GPIO.LOW):

# | | | | | | PowerOnReset(bus)

#The | following | is | | the | | power | plug | detection | judgment | | program | of | V1.1 | version. | GPIO | is

low | when | | power | | is | | plugged | in
if | (GPIO.input(4) | | | | | | | == | | GPIO.HIGH):
| | | | PowerOnReset(bus)
while | True:
print | "++++++++++++++++++++"
print | "Voltage:%5.2fV" | % | readVoltage(bus)
print | "Battery:%5i%%" | % | readCapacity(bus)
if | readCapacity(bus) | == | 100:
| | print | "Battery | FULL"
if | readCapacity(bus) | < | 5:
| | print | "Battery | LOW"
#The | following | is | | the | | power | plug | | detection | judgment | program | of | V1.0 | | version. | | GPIO | is

high | when | | power | | is | | plugged | | in
# | if | | (GPIO.input(4) | | == | | GPIO.HIGH):

# | | | | | | | | print | | "Power | Adapter | Plug | | In | | "

# | if | | (GPIO.input(4) | | == | | GPIO.LOW):

# | | | | | | | | print | | "Power | Adapter | Unplug"

#The | | following | is | | the | | power | plug | detection | judgment | | program | | of | V1.1 | version. | GPIO | is

low | | when | | power | | is | | plugged | in
| if | | (GPIO.input(4) | | | | | | | == | | GPIO.LOW):
| | | | | | | | print | "Power | | Adapter | | Plug | | In | "
| if | | (GPIO.input(4) | | | | | | | == | | GPIO.HIGH):
| | | | | | | | print | "Power | | Adapter | | Unplug"
print | "++++++++++++++++++++"
time.sleep(2)

Schematic Reference Part：

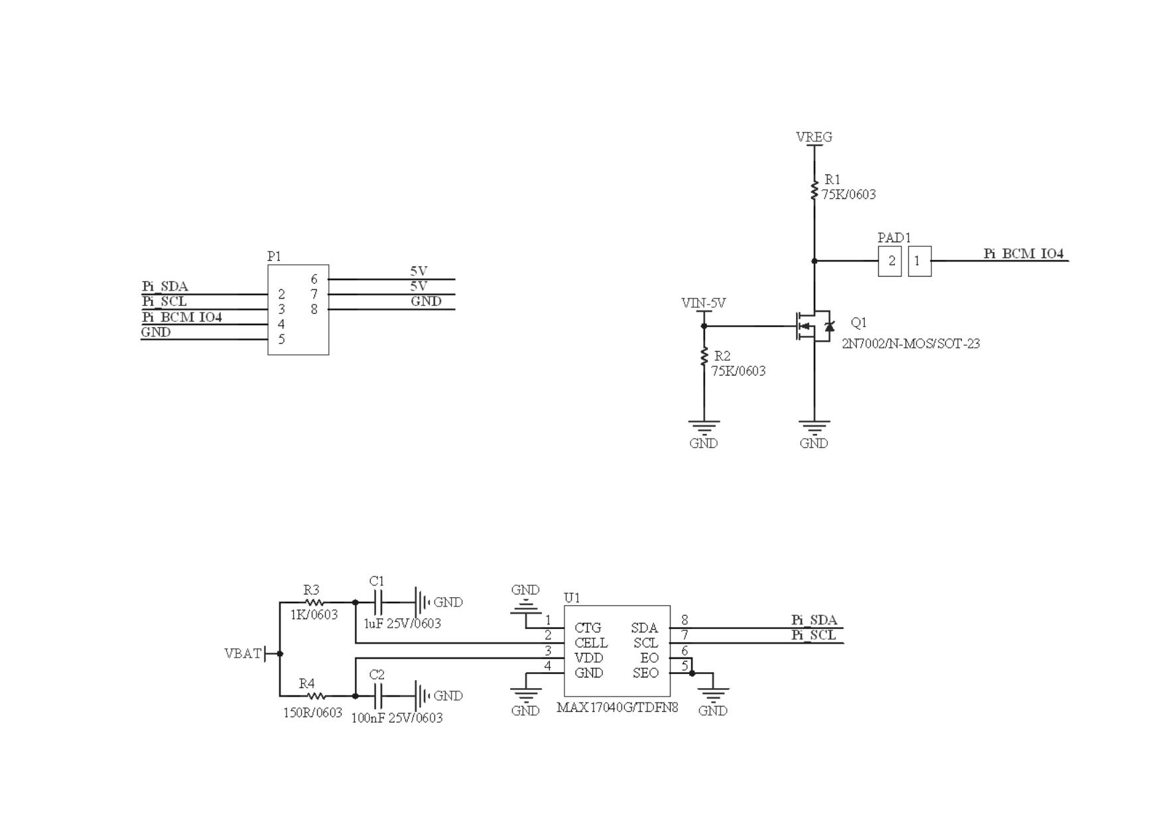
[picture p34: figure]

References：

MAX17040 Compact, low-cost 1S/2S fuel gauge - Maxim https://www.maximintegrated.com/cn/products/power/battery-management/MAX17040.html

If you have other questions, please contact me: 416386001@qq.com

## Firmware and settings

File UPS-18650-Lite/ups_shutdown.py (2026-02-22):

import smbus
import os
import time

# MAX17040G I2C address and registers
ADDR = 0x36
REG_VCELL = 0x02
REG_SOC = 0x04

bus = smbus.SMBus(1)

def read_capacity():
    # Read battery percentage (State of Charge)
    read = bus.read_word_data(ADDR, REG_SOC)
    swapped = ((read & 0xFF) << 8) | (read >> 8)
    return swapped / 256.0

while True:
    capacity = read_capacity()
    print(f"Battery Capacity: {capacity:.2f}%")
    
    if capacity <= 1.0:
        print("Low battery! Initiating safe shutdown...")
        os.system("sudo shutdown -h now")
        break
        
    time.sleep(60) # Check every minute

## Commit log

2026-02-22 Refactor README for improved clarity and structure
    Updated headings for better structure and clarity. Simplified instructions for fan control and UPS setup.
2026-02-22 Add 3d printed chassis models
    [barracuda.f3d, chassis.3mf, cover.3mf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]
2026-02-22 Add custom fan control circuit
2026-02-22 Improve README with table layout, chassis docs, and cleaner formatting
2026-02-23 Simplify shutdown instructions in SHUTDOWN.md
    Removed detailed instructions for shutdown methods and power indicators, retaining only essential information.
2026-02-23 Fix formatting of 40 Pin Stacking Header entry
